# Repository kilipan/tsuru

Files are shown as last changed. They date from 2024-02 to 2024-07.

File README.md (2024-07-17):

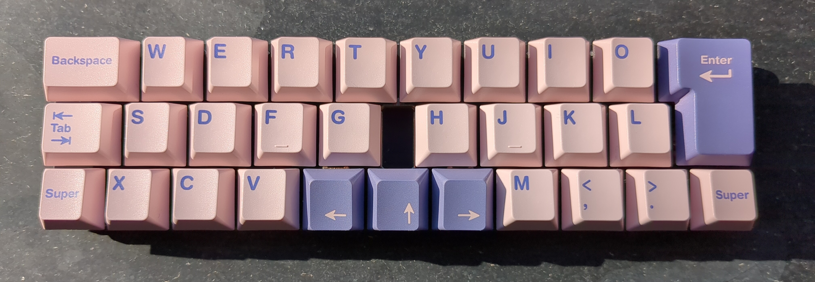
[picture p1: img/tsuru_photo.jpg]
tsuru


# 鶴の恩返し (Tsuru No Ongaeshi)
A cute lil 3-row, katana-staggered keyboard with ISO-Enter compat :)

## Versions
As of now there exist two confirmed versions in this repo:
- SAMD21 version (wired, ZMK only, you will have to flash a bootloader!)
- CH552T version (wired, FAK only)

An untested wireless version can be found in the ble branch.

An STM32F072 mod of the original SAMD21 version is available [here](https://github.com/calvin-mcd/tsuru-STM).

## Layout Options
Note: The CH552T version does not support the encoder!

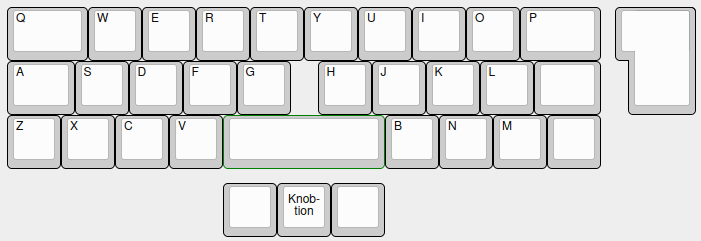
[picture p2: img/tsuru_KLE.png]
KLE


## Firmware
Firmware can be found in my respective repos:
- [FAK config](https://github.com/kilipan/fak-config/tree/main/keyboards/tsuru)
- [ZMK config](https://github.com/kilipan/zmk-config-tsuru)

## Cases
A beatiful wedge case (**NOT** pictured above) was made by DizzySkizzo (`dizzyskizzo1337` on Discord), who graciously allowed me to make it available under the same license. See the `case` directory.

A super fun case with a key strap and transport shell made by krisenplan is available [on printables](https://www.printables.com/de/model/946165-tsuru-travel-keyboard-case)!

Two great cases made by [Seirin-Blu](https://github.com/seirin-blu) are available here:
- [Tsuru MFR2](https://github.com/seirin-blu/Tsuru-MFR2)
- [SK-Tsuru](https://github.com/seirin-blu/SK-Tsuru)

## Availability
All files are provided under CERN-OHL-S license. Feel free to build your own!

## Thanks
Thank you Pete Johanson for letting me use the SAMD21 schematic and zmk config from the [samd21pad](https://github.com/petejohanson/samd21pad/) and for all the help getting the bootloader onto the chip!
This would've never gotten anywhere without your help <3

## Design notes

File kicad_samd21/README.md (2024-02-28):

tsuru

# 鶴の恩返し (Tsuru No Ongaeshi)
A cute lil 3-row, katana-staggered keyboard with ISO-Enter compat :)

## Layout Options
KLE

## BOM
| Amount | Part | LCSC part number | Schematic Designator |
|---:|:-----|:---|:---|
| 1 | Tsuru PCB | | | 
| 1 | Tsuru Plate | | | 
| 1 | ATSAMDE18A-AF | C618770 | U1 |
| 1 | SOT-23-5 Linear Voltage Regulator | C3021085 | U2 |
| 1 | Top-Mount USB-C Receptacle | C3001293 | J1 |
| 1 | SKQGAKE Button | C388858 | SW2 |
| 15 | BAV70 Diodes | C5184417 | D1, ..., D15 |
| 2 | 0805 1nF Capacitors | C129637 | C1, C3 |
| 1 | 0805 100nF Capacitor | C2169363 | C2 |
| 2 | 0805 5.1kΩ Resistors | C118848 | R1, R2 |
| 1 | 0805 1kΩ Resistor | C140870 | R3 |
|  30-31 | Kailh MX Hot Swap Sockets | C5184526 | MX1, ..., MX32|

## Bootloader
Since the SAMD21 doesn't come pre-flashed with a bootloader, you will have to flash one yourself.
The tested and confirmed working `.elf` file is available [right here](https://github.com/kilipan/tsuru/blob/main/bootloader-tsuru.elf).
You may flash it using `arm-none-eabi-gdb` with your favorite hardware debugger, using the following commands:
```sh
sudo -E arm-none-eabi-gdb path/to/bootloader-tsuru.elf
(gdb) target extended-remote /dev/ttyACM0
(gdb) mon swd_scan
(gdb) att 1
(gdb) mon erase
(gdb) load
(gdb) run
```
Depending on your setup and operating system, the name and number of your serial device may vary.

## Firmware
Tested and working [ZMK firmware](https://github.com/kilipan/zmk-config-tsuru) is available.

## Availability
All files are provided under CERN-OHL-S license. Feel free to build your own!

## Thanks
Thank you Pete Johanson for letting me use the SAMD21 schematic and zmk config from the [samd21pad](https://github.com/petejohanson/samd21pad/) and for all the help getting the bootloader onto the chip!
This would've never gotten anywhere without your help <3

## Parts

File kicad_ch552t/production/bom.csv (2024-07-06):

Designator | Footprint | Quantity | Value | LCSC Part #
C1, C2 | 0402 | 2 | 100nF | C1525
D1, D10, D11, D12, D13, D14, D15, D2, D3, D4, D5, D6, D7, D8, D9 | apfel_SOT-23_silkless | 15 | BAV70_Small
D16 | 0402 | 1 | PMEG2010EA | C2837790
F1 | 0402 | 1 | 500mA | C18198354
H1, H2, H3, H4 | MountingHole_2.2mm_M2_Pad_Via_nosilk | 4 | MountingHole_Pad
J1 | USB_C_Receptacle_HRO_TYPE-C-31-M-12 | 1 | USB_C_Receptacle_USB2.0 | C2765186
MX1, MX10, MX11, MX12, MX13, MX14, MX15, MX16, MX17, MX18, MX19, MX2, MX20, MX21, MX22, MX23, MX24, MX25, MX26, MX27, MX28, MX29, MX3, MX30, MX31, MX32, MX4, MX5, MX6, MX7, MX8, MX9 | MX-HotswapSAFE_no_silk | 32 | MX_SW_HS | C5184526
R1, R2 | 0402 | 2 | 5.1k | C25905
R3 | 0402 | 1 | 10k | C25744
S1 | STAB_MX_P_3u | 1 | MX_stab
S2 | STAB_MX_ISO-ROT | 1 | MX_stab
SW1 | SW_Push_SPST_NO_Alps_SKRK | 1 | BOOT | C115357
SW2 | SW_Push_SPST_NO_Alps_SKRK | 1 | RESET | C115357
U1 | TSSOP-20_4.4x6.5mm_P0.65mm | 1 | ~ | C111367
U2 | SOT-23-6 | 1 | USBLC6-2SC6 | C2687116

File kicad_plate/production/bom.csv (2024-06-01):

Designator | Footprint | Quantity | Value | LCSC Part #
H1, H2, H3, H4 | MountingHole_3.2mm_M3 | 4 | MountingHole

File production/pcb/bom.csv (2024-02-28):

Designator | Footprint | Quantity | Value | LCSC Part #
C1, C3 | 0805 | 2 | 1nF | C129637
C2 | 0805 | 1 | 100nF | C2169363
D1, D10, D11, D12, D13, D14, D15, D2, D3, D4, D5, D6, D7, D8, D9 | SOT-23 | 15 | BAV70_Small | C5184417
J1 | USB_C_Receptacle_GT-USB-7010 | 1 | USB_C_Receptacle_USB2.0 | C3001293
R1, R2 | 0805 | 2 | 5.1k | C118848
R3 | 0805 | 1 | 1k | C140870
SW2 | SW_SPST_SKQG_WithStem | 1 | SKQGAKE020 | C388858
U1 | TQFP-32_7x7mm_P0.8mm | 1 | ATSAMD21E18A-AF | C618770
U2 | SOT-23-5 | 1 | AP2112K-3.3 | C3021085

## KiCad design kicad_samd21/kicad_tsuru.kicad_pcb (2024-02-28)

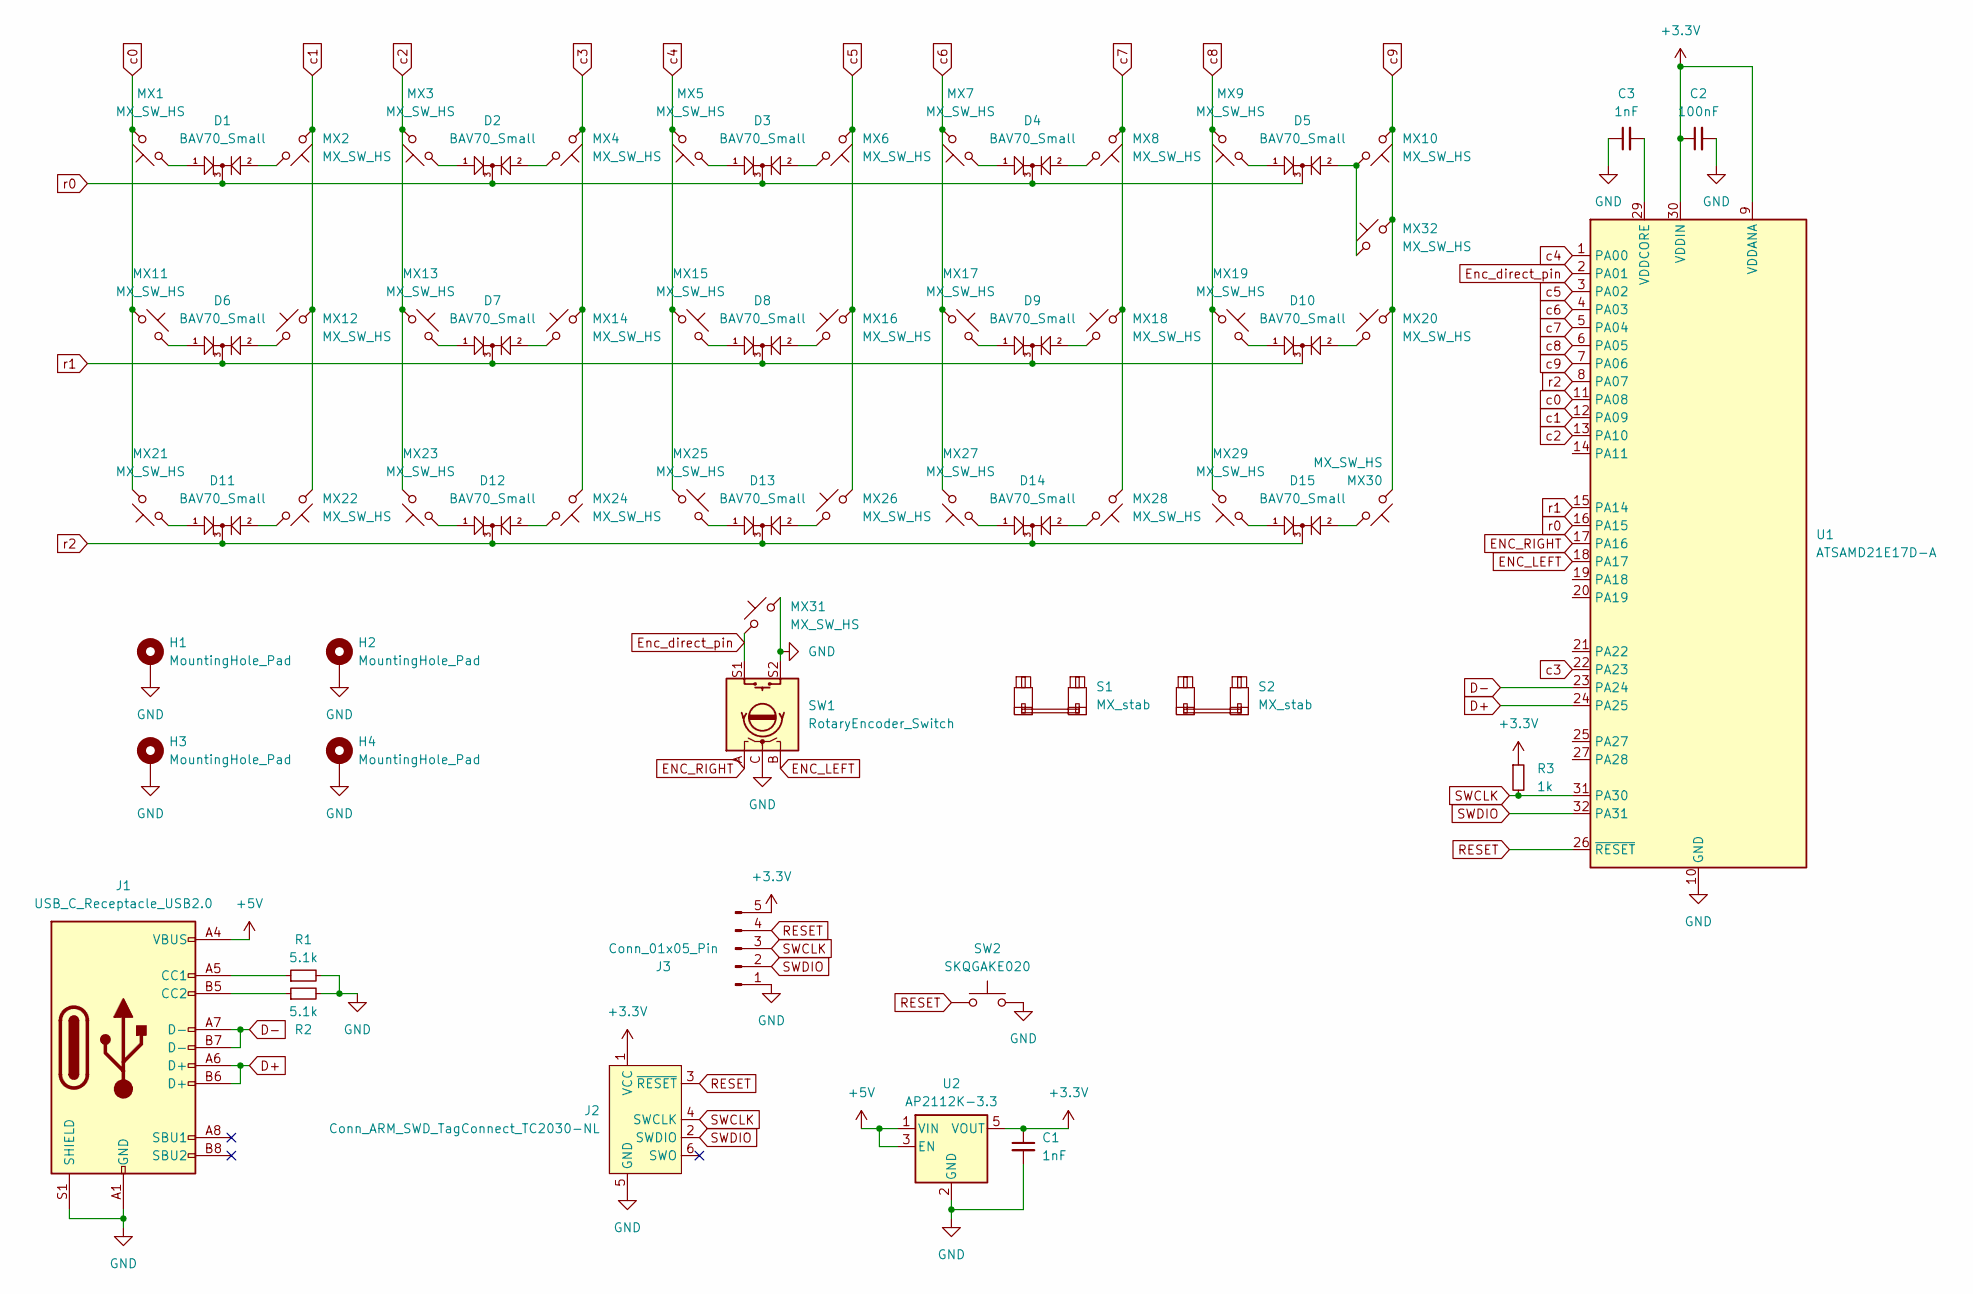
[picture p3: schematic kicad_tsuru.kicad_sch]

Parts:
C1, C3: 1nF; C_0805_2012Metric_Pad1.18x1.45mm_HandSolder; LCSC Part Number C129637
C2: 100nF; C_0805_2012Metric_Pad1.18x1.45mm_HandSolder; LCSC Part Number C2169363
D1, D2, D3, D4, D5, D6, D7, D8, D9, D10, D11, D12, D13, D14, D15: BAV70_Small; apfel_SOT-23_silkless
H1, H2, H3, H4: MountingHole_Pad; MountingHole_2.2mm_M2_Pad_Via_nosilk
J1: USB_C_Receptacle_USB2.0; USB_C_Receptacle_GT-USB-7010; LCSC Part Number C3001293
J2: Conn_ARM_SWD_TagConnect_TC2030-NL; Tag-Connect_TC2030-IDC-NL_2x03_P1.27mm_Vertical
J3: Conn_01x05_Pin; PinHeader_1x05_P2.54mm_Vertical
MX1, MX2, MX3, MX4, MX5, MX6, MX7, MX8, MX9, MX10, MX11, MX12, MX13, MX14, MX15, MX16, MX17, MX18, MX19, MX20, MX21, MX22, MX23, MX24, MX25, MX26, MX27, MX28, MX29, MX30, MX31, MX32: MX_SW_HS; MX-HotswapSAFE_no_silk
R1, R2: 5.1k; R_0805_2012Metric_Pad1.20x1.40mm_HandSolder
R3: 1k; R_0805_2012Metric_Pad1.20x1.40mm_HandSolder
S1: MX_stab; STAB_MX_P_3u
S2: MX_stab; STAB_MX_ISO-ROT
SW1: RotaryEncoder_Switch; ROT_Alps_EC11E-Switch_noMP_nosilk
SW2: SKQGAKE020; SW_SPST_SKQG_WithStem; MPN SKQGAKE020; LCSC Part Number C388858
U1: ATSAMD21E17D-A; TQFP-32_7x7mm_P0.8mm; MPN ATSAMD21E17D-A
U2: AP2112K-3.3; SOT-23-5; MPN AP2112K-3.3; LCSC Part Number C3021085

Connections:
+3.3V: C1.1, C2.1, J2.1 (VCC), J3.5, R3.1, U1.9 (VDDANA), U1.30 (VDDIN), U2.5 (VOUT)
+5V: J1.A4 (VBUS), J1.A9 (VBUS), J1.B4 (VBUS), J1.B9 (VBUS), U2.1 (VIN), U2.3 (EN)
D+: J1.A6 (D+), J1.B6 (D+), U1.24 (PA25)
D-: J1.A7 (D-), J1.B7 (D-), U1.23 (PA24)
ENC_LEFT: SW1.B, U1.18 (PA17)
ENC_RIGHT: SW1.A, U1.17 (PA16)
Enc_direct_pin: MX31.1, SW1.S1, U1.2 (PA01)
GND: C1.2, C2.2, C3.1, H1.1, H2.1, H3.1, H4.1, J1.A1 (GND), J1.A12 (GND), J1.B1 (GND), J1.B12 (GND), J1.S1 (SHIELD), J2.5 (GND), J3.1, MX31.2, R1.2, R2.2, SW1.C, SW1.S2, SW2.2, U1.10 (GND), U1.28 (GND), U2.2 (GND)
unnamed: D1.1 (A1), MX1.1
unnamed: D1.2 (A2), MX2.2
unnamed: D2.1 (A1), MX3.1
unnamed: D2.2 (A2), MX4.2
unnamed: D3.1 (A1), MX5.1
unnamed: D3.2 (A2), MX6.2
unnamed: D4.1 (A1), MX7.1
unnamed: D4.2 (A2), MX8.2
unnamed: D5.1 (A1), MX9.1
unnamed: D5.2 (A2), MX10.2, MX32.1
unnamed: D6.1 (A1), MX11.2
unnamed: D6.2 (A2), MX12.1
unnamed: D7.1 (A1), MX13.2
unnamed: D7.2 (A2), MX14.1
unnamed: D8.1 (A1), MX15.2
unnamed: D8.2 (A2), MX16.1
unnamed: D9.1 (A1), MX17.2
unnamed: D9.2 (A2), MX18.1
unnamed: D10.1 (A1), MX19.2
unnamed: D10.2 (A2), MX20.1
unnamed: D11.1 (A1), MX21.1
unnamed: D11.2 (A2), MX22.2
unnamed: D12.1 (A1), MX23.1
unnamed: D12.2 (A2), MX24.2
unnamed: D13.1 (A1), MX25.2
unnamed: D13.2 (A2), MX26.1
unnamed: D14.1 (A1), MX27.1
unnamed: D14.2 (A2), MX28.2
unnamed: D15.1 (A1), MX29.1
unnamed: D15.2 (A2), MX30.2
unnamed: J1.A5 (CC1), R1.1
unnamed: J1.B5 (CC2), R2.1
unnamed: C3.2, U1.29 (VDDCORE)
RESET: J2.3 (~RESET), J3.4, SW2.1, U1.26 (~RESET)
SWCLK: J2.4 (SWCLK), J3.3, R3.2, U1.31 (PA30)
SWDIO: J2.2 (SWDIO), J3.2, U1.32 (PA31)
c0: MX1.2, MX11.1, MX21.2, U1.11 (PA08)
c1: MX2.1, MX12.2, MX22.1, U1.12 (PA09)
c2: MX3.2, MX13.1, MX23.2, U1.13 (PA10)
c3: MX4.1, MX14.2, MX24.1, U1.22 (PA23)
c4: MX5.2, MX15.1, MX25.1, U1.1 (PA00)
c5: MX6.1, MX16.2, MX26.2, U1.3 (PA02)
c6: MX7.2, MX17.1, MX27.2, U1.4 (PA03)
c7: MX8.1, MX18.2, MX28.1, U1.5 (PA04)
c8: MX9.2, MX19.1, MX29.2, U1.6 (PA05)
c9: MX10.1, MX20.2, MX30.1, MX32.2, U1.7 (PA06)
r0: D1.3 (K), D2.3 (K), D3.3 (K), D4.3 (K), D5.3 (K), U1.16 (PA15)
r1: D6.3 (K), D7.3 (K), D8.3 (K), D9.3 (K), D10.3 (K), U1.15 (PA14)
r2: D11.3 (K), D12.3 (K), D13.3 (K), D14.3 (K), D15.3 (K), U1.8 (PA07)

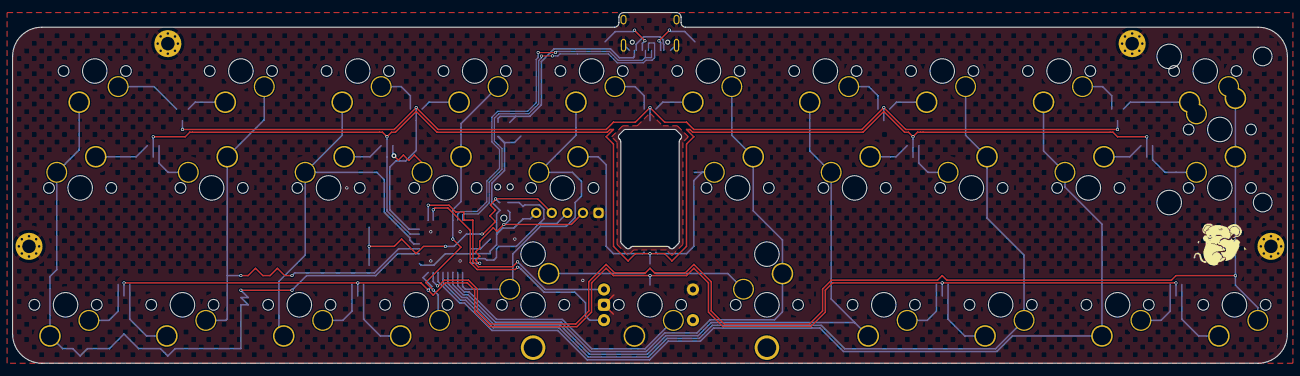
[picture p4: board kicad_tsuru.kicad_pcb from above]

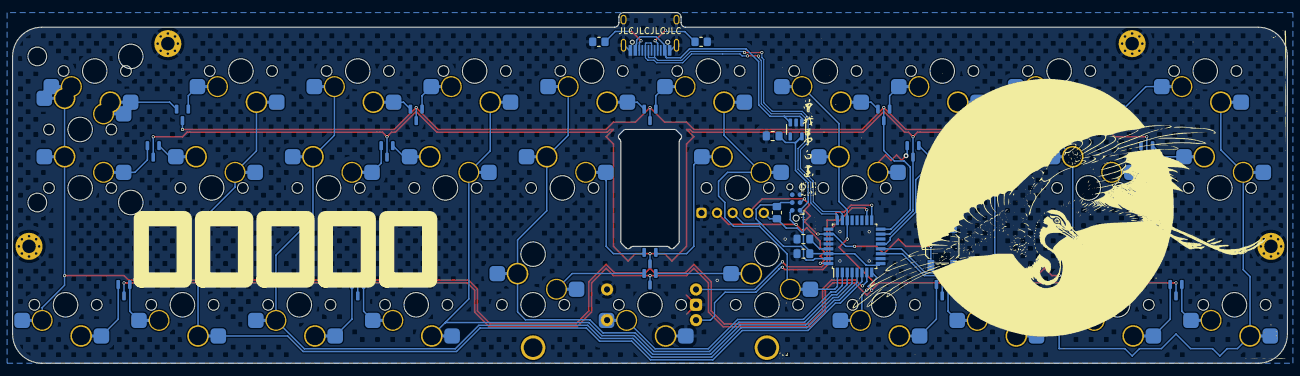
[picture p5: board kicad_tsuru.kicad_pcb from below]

Board: 2 copper layers, 207.8 x 57.2 mm, 67 parts (27 on the bottom side), 57 nets.

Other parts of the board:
tsuru: LOGO

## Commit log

2024-03-15 add budget version
    [bom.csv, designators.csv, kicad_ch552t.kicad_pcb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]
2024-04-11 fix hs socket assembly side
    [bom.csv, positions.csv]
2024-04-28 add case; housekeeping
    [kicad_tsuru.kicad_pcb, kicad_tsuru.kicad_sch]
2024-06-01 add holes for reaching pcb screws
    [bom.csv, designators.csv, kicad_tsuru_plate.kicad_pcb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]
2024-06-01 mention krisenplan case
2024-06-18 fix plate file
    [kicad_tsuru_plate.kicad_pcb]
2024-07-17 Add link to krisenplan case to README.md
